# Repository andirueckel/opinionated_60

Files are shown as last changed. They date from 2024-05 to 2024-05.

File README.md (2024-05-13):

# opinionated_60

The opinionated_60 is a fixed-layout ANSI-based 60% mechanical keyboard PCB for *Cherry MX*-style switches with split `BACKSPACE`, split `RIGHT_SHIFT`, and 7u `SPACE` bar; there’s **no** option for a stepped `CAPS_LOCK` key.

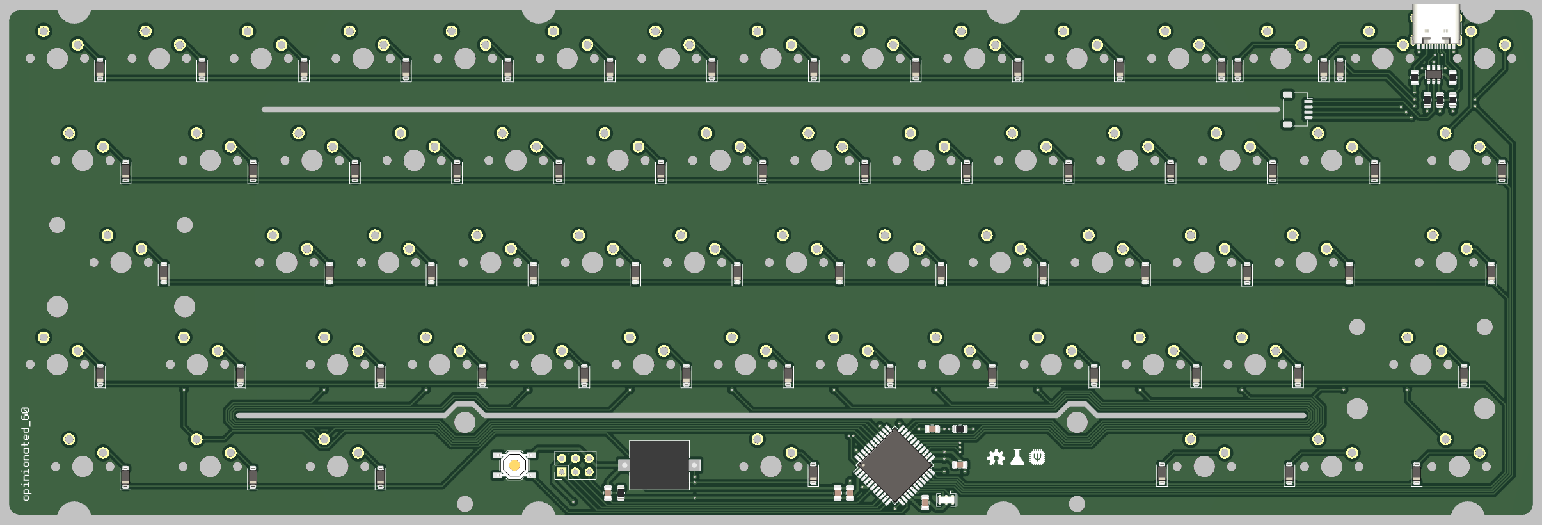
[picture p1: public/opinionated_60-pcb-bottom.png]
image/opinionated_60 pcb bottom view


The opinionated_60 is a rather modified, stripped-down, cleaned-up, and re-wired revision of the [Plain60 MKD Edition](https://github.com/manzel/plain60-mkd-edition) (ANSI version) by [manzel](https://github.com/manzel), which itself is a modified version of the [Plain60 Flex Edition](https://github.com/evyd13/plain60-flex-edition) (rev2.2) by [evyd13](https://github.com/evyd13).

The PCB design and schematics were created in [KiCad 8.0.2](https://www.kicad.org/blog/2024/04/KiCad-8.0.2-Release/).

## Features

  - Fits the SINGAKBD × TGR Unikorn and the HAYTCO CAKE60! <3
  - QMK and Vial support via the respective [firmware](/firmware)
  - No LEDs, no RGB, and no underglow!
  - *n*-key rollover (NKRO)

Also fits most universal 60% cases (Mekanisk Klippe & Fjell, KBDfans Tofu, etc.), where *fits* means *Unikorn*-style *gummy o-ring friction fit*, not traditional *tray mount* as there’s **no** holes for screws! Consider universal 60% case support experimental, and please do your research regarding your specific (use) case.

## Specifications

  - ATmega32U4-AU microcontroller
  - USB 2.0 Type-C connector *(default)*, and/or
  - JST connector for unified daughterboard *(optional)*
  - ESD protection chip and fuse to protect the PCB
  - ISP pin holes for flashing [QMK](https://github.com/qmk/qmk_firmware) and [Vial](https://github.com/vial-kb/vial-qmk) firmware
  - AST1109MLTRQ audio indicator (piezo buzzer/speaker) *(optional)*

## Layout

The 7u bottom row can be configured as *blockerless*, *WKL (winkeyless)*, or *HHKB*-style.

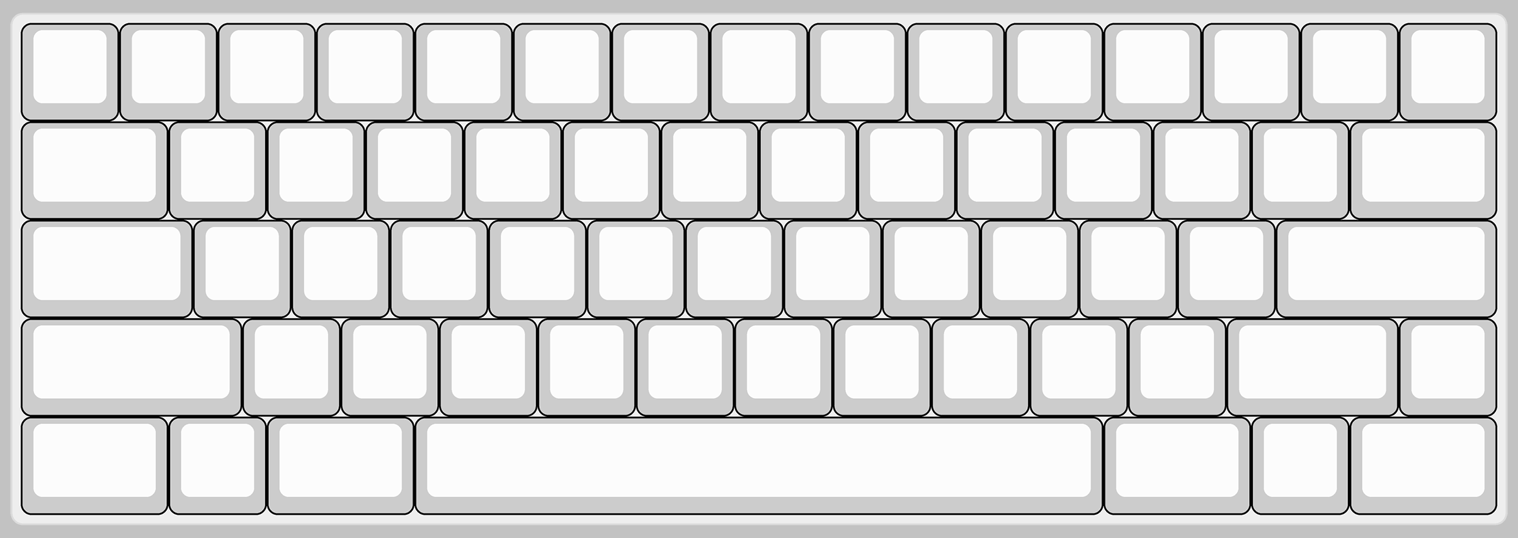
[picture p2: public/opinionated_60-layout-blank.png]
image/opinionated_60 key layout blank


## Plate

The plate drawings were created in KiCad’s PCB design tool and could be manufactured as “PCB” from e.g. aluminum base material or regular FR-4 in any color. CNC-machining the plate has not been attempted, yet.

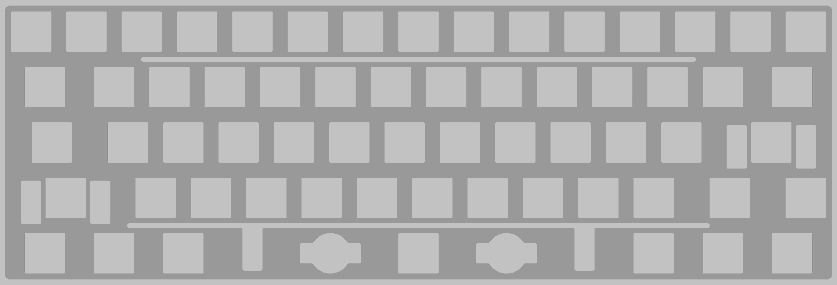
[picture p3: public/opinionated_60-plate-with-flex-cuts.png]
image/opinionated_60 plate with flex cuts


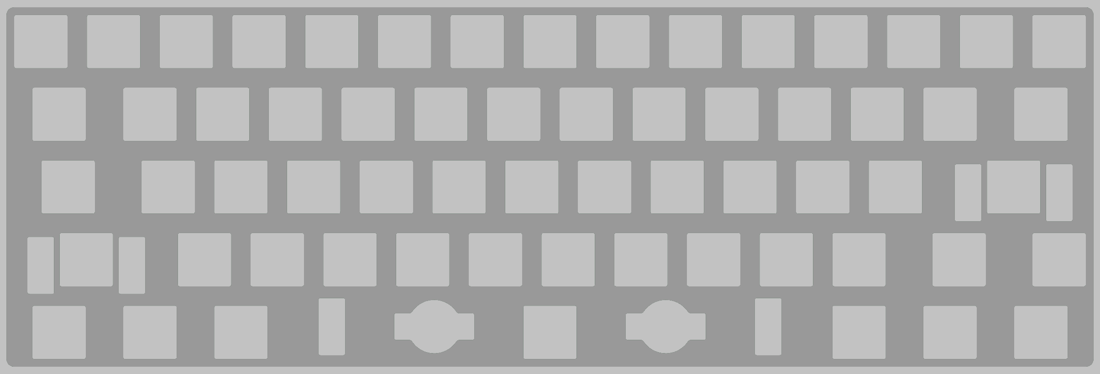
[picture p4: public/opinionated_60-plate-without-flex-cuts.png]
image/opinionated_60 plate without flex cuts


## Production

PCB and plate production files for can be found in the [Gerber](/hardware/Gerber) directory.

The production files were generated via [JLCKicadTools](https://github.com/matthewlai/JLCKicadTools).

## DISCLAIMER

Absolutely no guarantee for anything.

Use at your own risk!

## LICENSE

Creative Commons Attribution Share Alike 4.0 International (CC-BY-SA-4.0)

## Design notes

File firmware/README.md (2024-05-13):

# opinionated_60

The [opinionated_60](/) is a fixed-layout ANSI-based 60% mechanical keyboard PCB for *Cherry MX*-style switches with split `BACKSPACE`, split `RIGHT_SHIFT`, and 7u `SPACE` bar; there’s **no** option for a stepped `CAPS_LOCK` key.

image/opinionated_60 pcb bottom view

## QMK

> [!NOTE]
> The following commands needs to be executed in [`qmk_firmware`](https://github.com/qmk/qmk_firmware) context.

Navigate to your local `qmk_firmware` directory/repository:

    cd ~/path/to/qmk_firmware/

Let `qmk_firmware` know about the opinionated_60 keyboard:

    ln -s ~/path/to/opinionated_60/firmware ./keyboards/opinionated_60

Make example for this keyboard (after setting up your build environment):

    make opinionated_60:default

Flashing example for this keyboard:

    make opinionated_60:default:flash

See the QMK [build environment setup](https://docs.qmk.fm/#/getting_started_build_tools) and the [make instructions](https://docs.qmk.fm/#/getting_started_make_guide) for more information.

Brand new to QMK? Start with our [Complete Newbs Guide](https://docs.qmk.fm/#/newbs).

## Vial

> [!NOTE]
> The following commands needs to be executed in [`vial-qmk`](https://github.com/vial-kb/vial-qmk) context.

Navigate to your local `vial-qmk` directory/repository:

    cd ~/path/to/vial-qmk/

Let `vial-qmk` know about the opinionated_60 keyboard:

    ln -s ~/path/to/opinionated_60/firmware ./keyboards/opinionated_60

Make example for this keyboard (after setting up your build environment):

    make opinionated_60:vial

Flashing example for this keyboard:

    make opinionated_60:vial:flash

See the Vial [build environment setup](https://get.vial.today/docs/porting-to-vial.html#1-prepare-your-build-environment) and the [make instructions](https://get.vial.today/docs/porting-to-vial.html#1-prepare-your-build-environment) for more information.

Brand new to Vial/QMK? Start with the QMK [Complete Newbs Guide](https://docs.qmk.fm/#/newbs).

> [!NOTE]
> The Vial [secure unlock combination](https://get.vial.today/docs/porting-to-vial.html#6-set-up-a-secure-unlock-combination) is defined in [`/firmware/keymaps/vial/config.h`](/firmware/keymaps/vial/config.h).

## Bootloader

There’s two ways to enter the bootloader:

- **Physical reset button**: Press/Hold the button on the back of the PCB when connecting the USB.
- **Bootmagic reset key**: Press/Hold the `ENTER` key/switch on the keyboard when connecting the USB.

> [!NOTE]
> The [Bootmagic reset key](https://docs.qmk.fm/#/reference_info_json?id=bootmagic) is defined in [`/firmware/info.json`](/firmware/info.json).

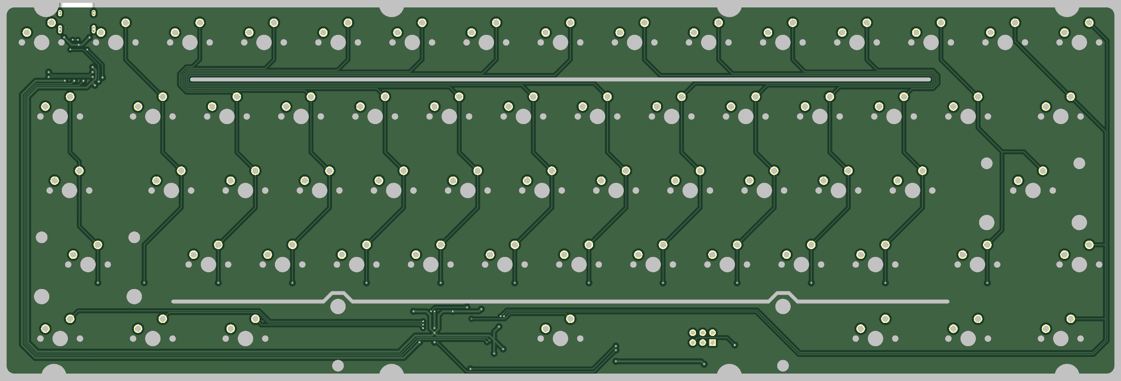
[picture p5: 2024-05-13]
public/opinionated_60-pcb-top.png

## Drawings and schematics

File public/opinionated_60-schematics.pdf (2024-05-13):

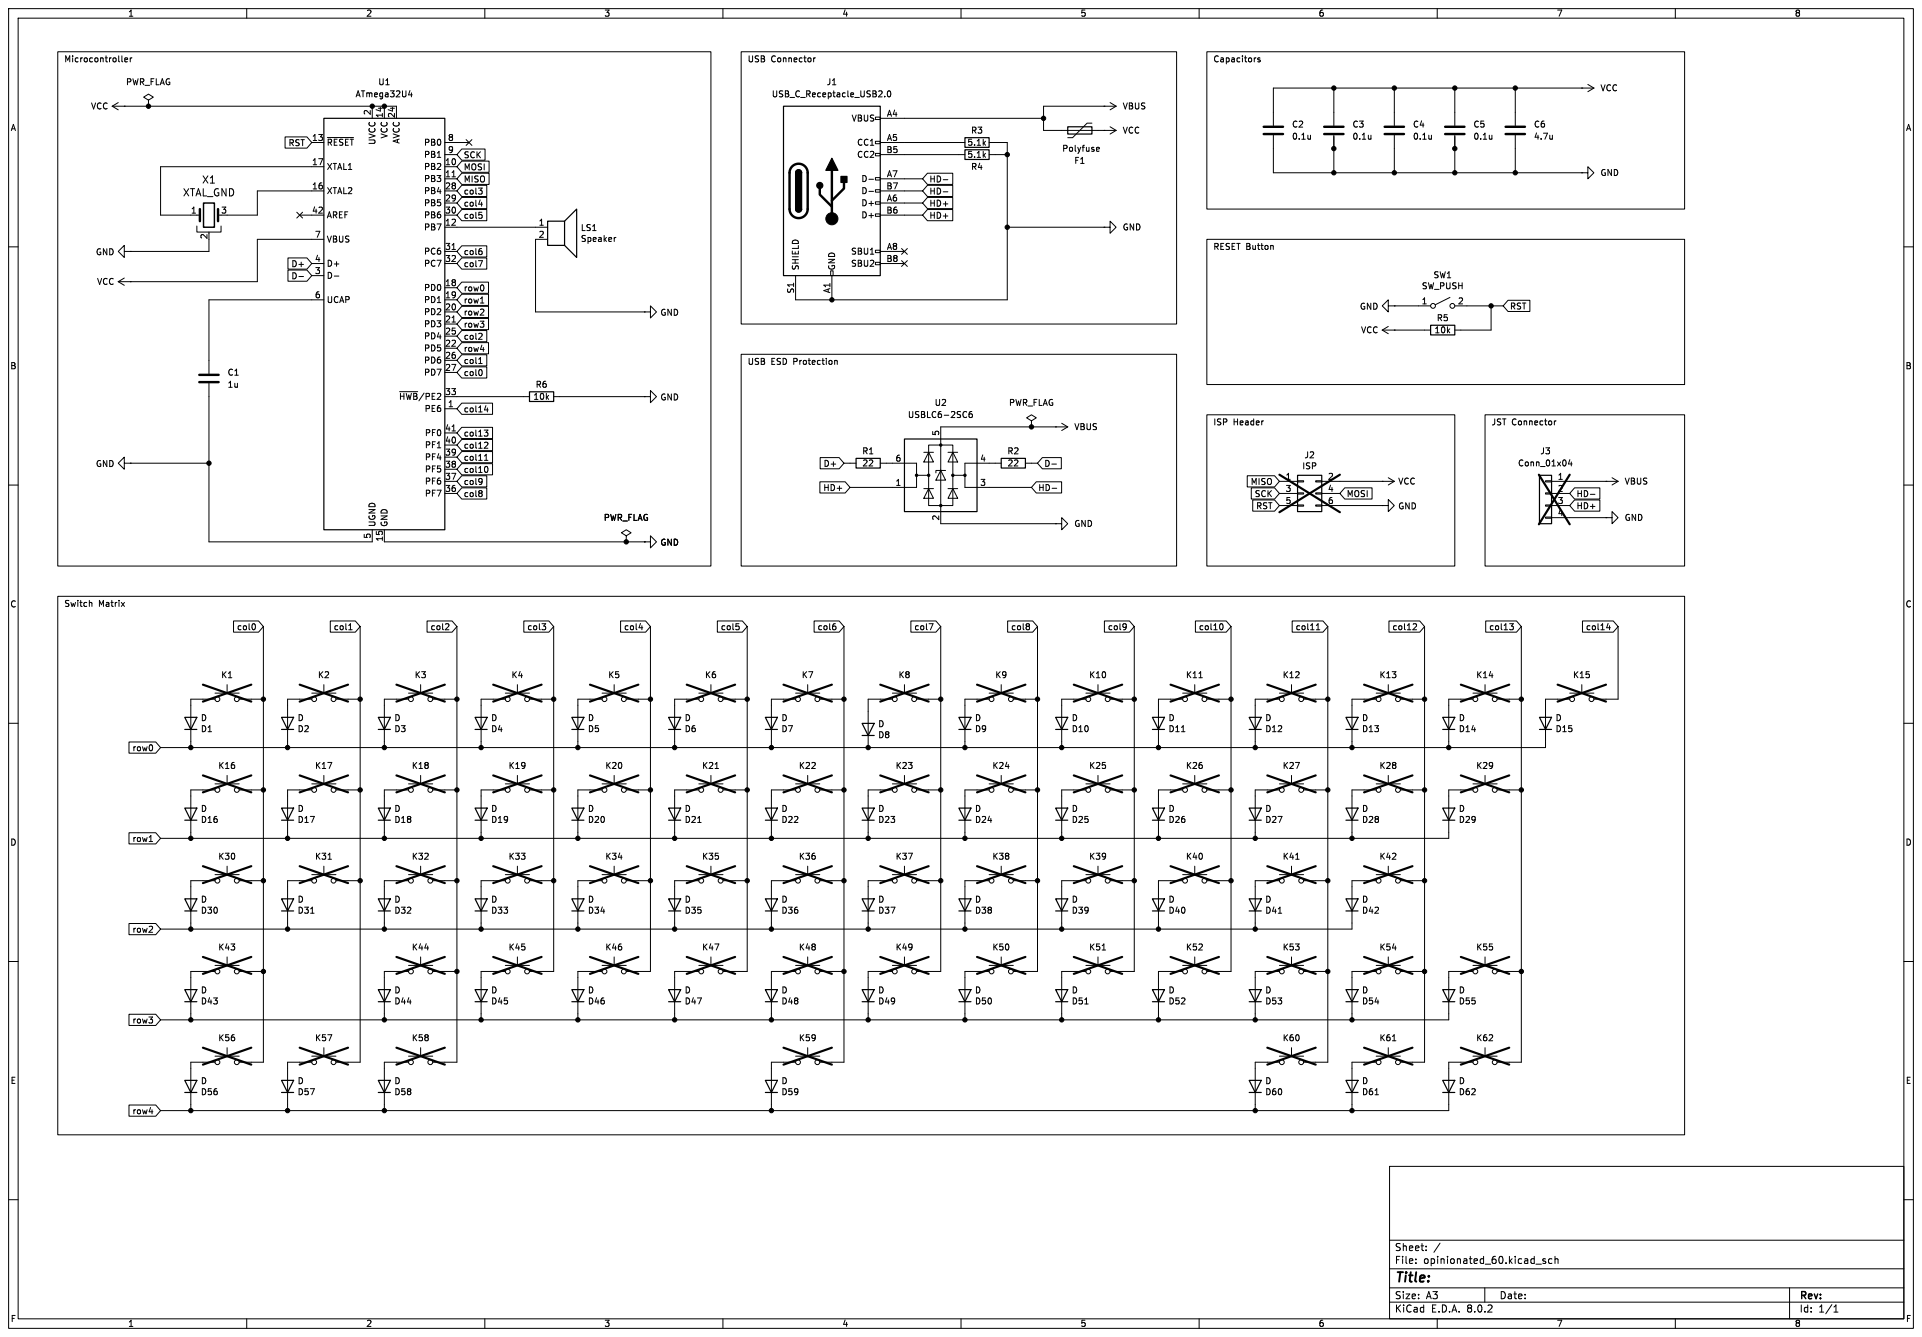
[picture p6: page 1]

2 PD2 20 PD3 21 PD5 22 AVCC 24 PD4 25 PD6 26 PD7 27 PB4 28 PB5 29 D- 3 PB6 30 PC6 31 PC7 32 ~{HWB}/PE233 PF7 36 PF6 37 PF5 38 PF4 39 D+ 4 PF1 40 PF0 41 AREF 42 UGND

Id: 1/1 Title: File: opinionated_60.kicad_sch Sheet: /

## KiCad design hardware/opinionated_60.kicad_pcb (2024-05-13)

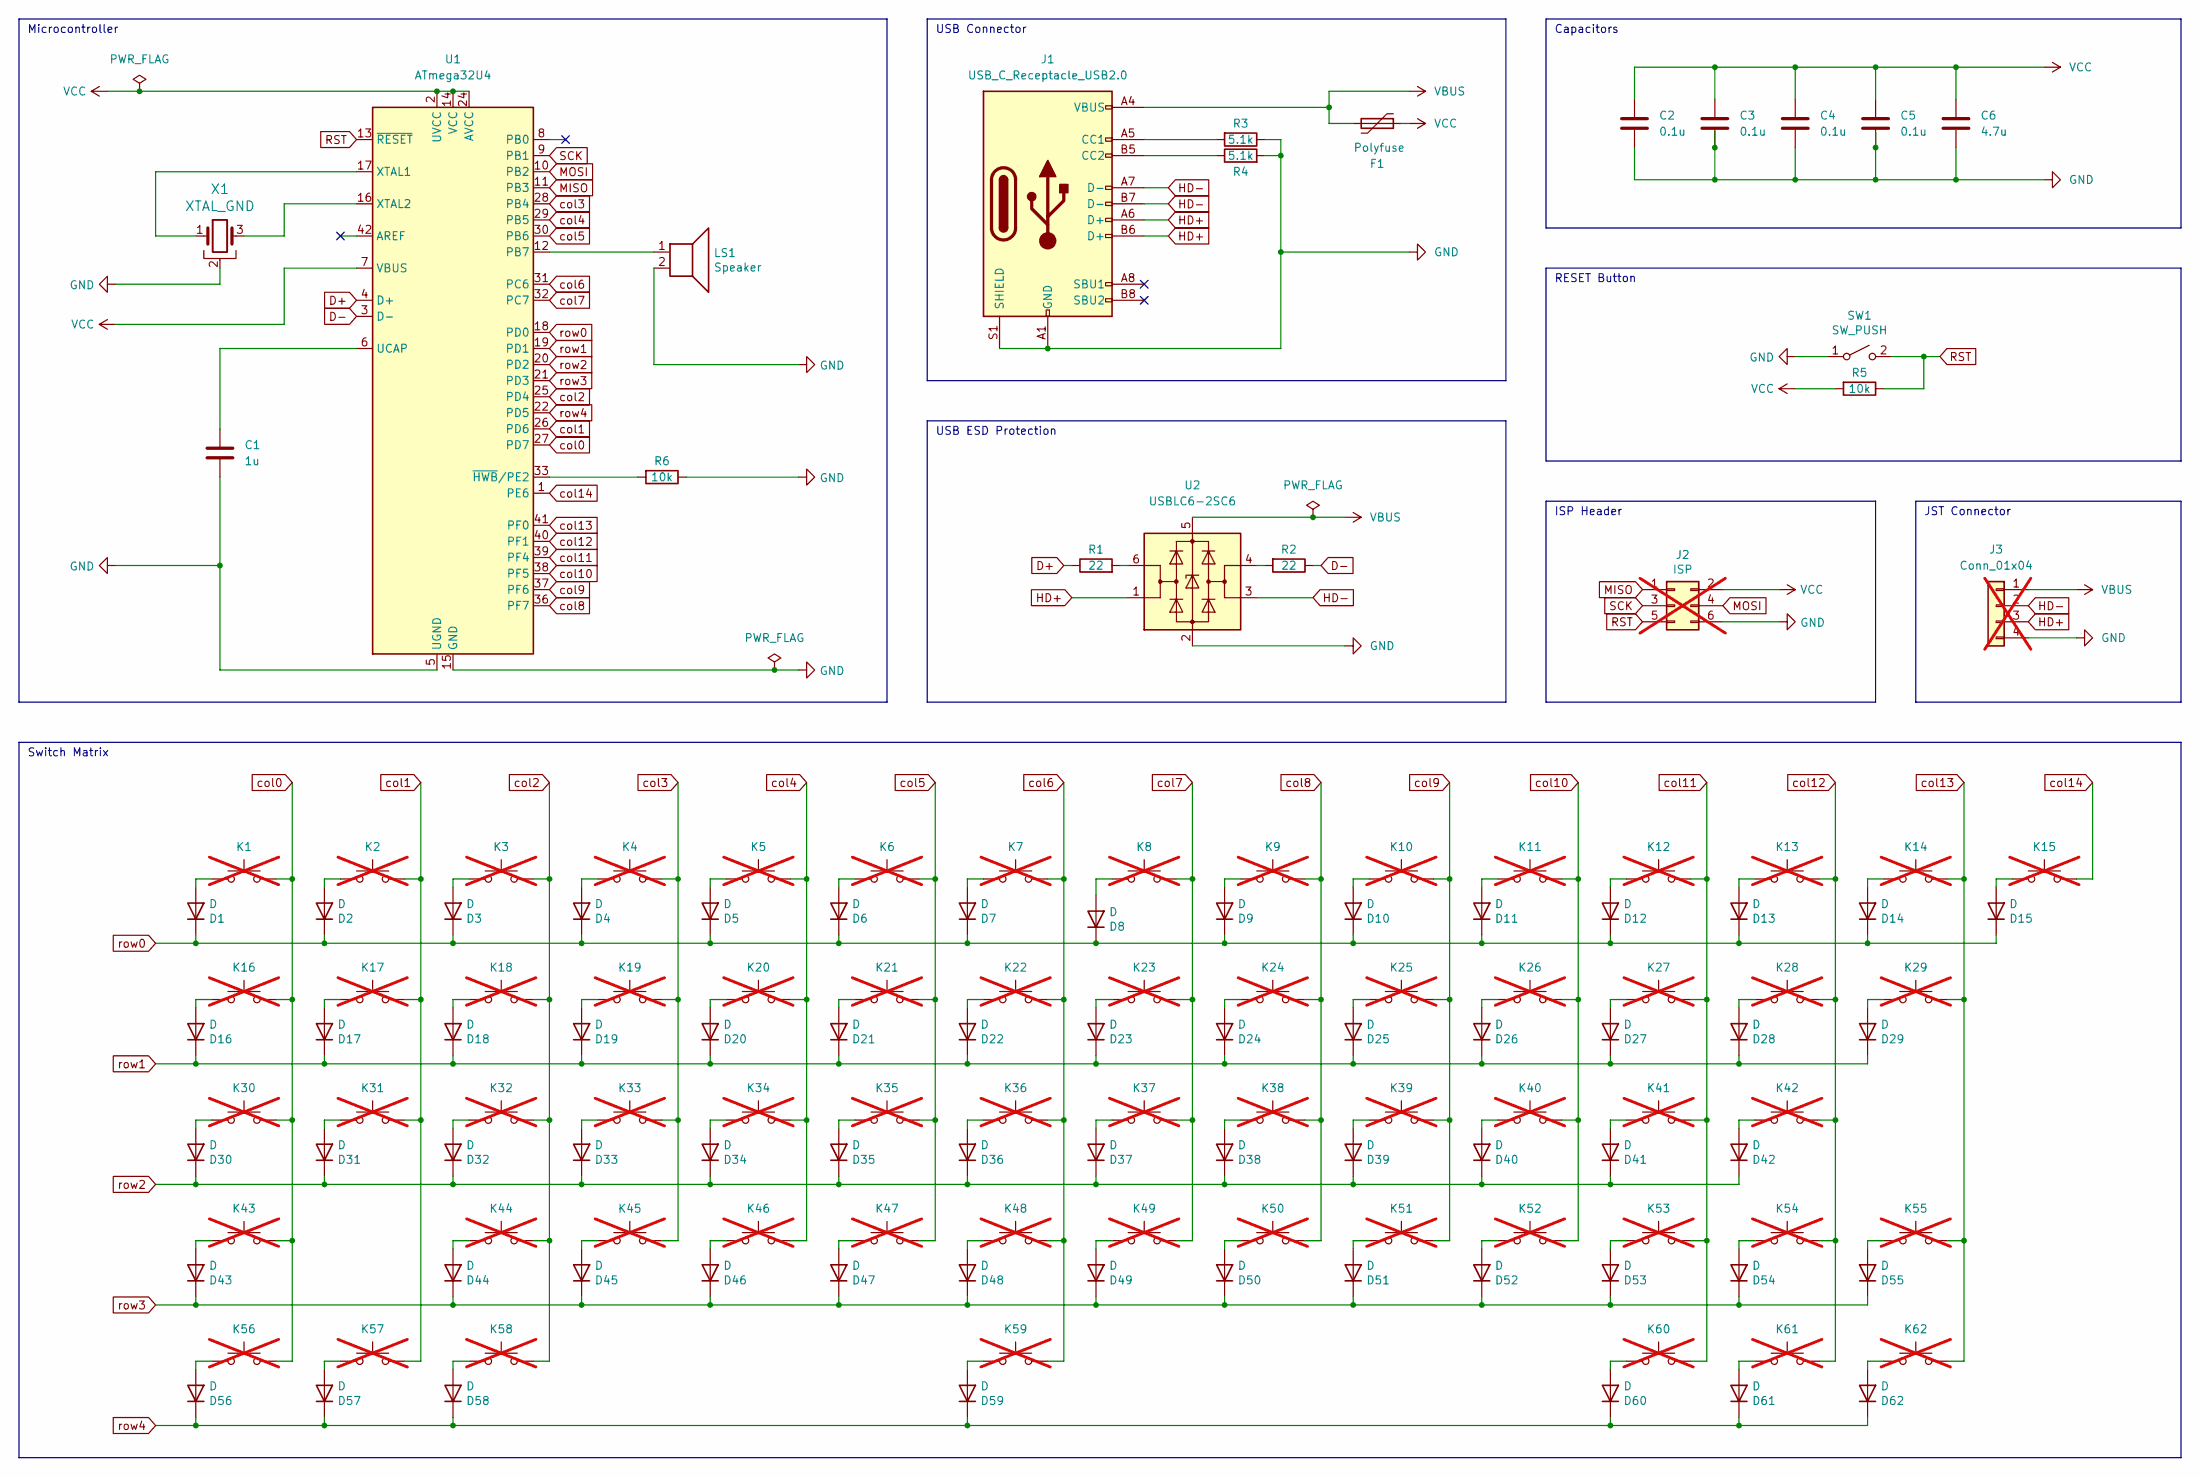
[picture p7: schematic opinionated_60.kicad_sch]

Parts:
C1: 1u; C_0805_2012Metric; LCSC part number C28323
C2, C3, C4, C5: 0.1u; C_0805_2012Metric; LCSC part number C49678
C6: 4.7u; C_0805_2012Metric; LCSC part number C1779
D1, D2, D3, D4, D5, D6, D7, D8, D9, D10, D11, D12, D13, D14, D15, D16, D17, D18, D19, D20, D21, D22, D23, D24, D25, D26, D27, D28, D29, D30, D31, D32, D33, D34, D35, D36, D37, D38, D39, D40, D41, D42, D43, D44, D45, D46, D47, D48, D49, D50, D51, D52, D53, D54, D55, D56, D57, D58, D59, D60, D61, D62: D; D_SOD-123; LCSC part number C2099
F1: Polyfuse; Fuse_0805_2012Metric; LCSC part number C261942
J1: USB_C_Receptacle_USB2.0; USB_C_Receptacle_HRO_TYPE-C-31-M-12; LCSC part number C165948
J2: ISP; PinHeader_2x03_P2.54mm_Vertical; not fitted
J3: Conn_01x04; JST_SH_SM04B-SRSS-TB_1x04-1MP_P1.00mm_Horizontal; LCSC part number C160404; not fitted
K1, K2, K3, K4, K5, K6, K7, K8, K9, K10, K11, K12, K13, K14, K15, K17, K18, K19, K20, K21, K22, K23, K24, K25, K26, K27, K28, K31, K32, K33, K34, K35, K36, K37, K38, K39, K40, K41, K44, K45, K46, K47, K48, K49, K50, K51, K52, K53, K55, K57, K61: SW_KEY; SW_Cherry_MX_1.00u_PCB; not fitted
K16, K29, K56, K58, K60, K62: SW_KEY; SW_Cherry_MX_1.50u_PCB; not fitted
K30, K54: SW_KEY; SW_Cherry_MX_1.75u_PCB; not fitted
K42, K43: SW_KEY; SW_Cherry_MX_2.25u_PCB; not fitted
K59: SW_KEY; SW_Cherry_MX_7.00u_PCB; not fitted
LS1: Speaker; Buzzer_Mallory_AST1109MLTRQ; LCSC part number C391036
R1, R2: 22; R_0805_2012Metric; LCSC part number C17561
R3, R4: 5.1k; R_0805_2012Metric; LCSC part number C27834
R5, R6: 10k; R_0805_2012Metric; LCSC part number C17414
SW1: SW_PUSH; SW_SPST_TL3342; LCSC part number C92584
U1: ATmega32U4; TQFP-44_10x10mm_P0.8mm; LCSC part number C44854
U2: USBLC6-2SC6; SOT-23-6; LCSC part number C7519
X1: XTAL_GND; Resonator_SMD_Murata_CSTxExxV-3Pin_3.0x1.1mm; LCSC part number C783275

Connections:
D+: R1.1, U1.4 (D+)
D-: R2.1, U1.3 (D-)
GND: C1.2, C2.2, C3.2, C4.2, C5.2, C6.2, J1.A1 (GND), J1.A12 (GND), J1.B1 (GND), J1.B12 (GND), J1.S1 (SHIELD), J2.6, J3.4, LS1.2, R3.1, R4.2, R6.1, SW1.1 (A), U1.5 (UGND), U1.15 (GND), U1.23 (GND), U1.35 (GND), U1.43 (GND), U2.2 (GND), X1.2
HD+: J1.A6 (D+), J1.B6 (D+), J3.3, U2.1 (I/O1)
HD-: J1.A7 (D-), J1.B7 (D-), J3.2, U2.3 (I/O2)
MISO: J2.1, U1.11 (PB3)
MOSI: J2.4, U1.10 (PB2)
unnamed: D1.2 (A), K1.2
unnamed: D2.2 (A), K2.2
unnamed: D3.2 (A), K3.2
unnamed: D4.2 (A), K4.2
unnamed: D5.2 (A), K5.2
unnamed: D6.2 (A), K6.2
unnamed: D7.2 (A), K7.2
unnamed: D8.2 (A), K8.2
unnamed: D9.2 (A), K9.2
unnamed: D10.2 (A), K10.2
unnamed: D11.2 (A), K11.2
unnamed: D12.2 (A), K12.2
unnamed: D13.2 (A), K13.2
unnamed: D14.2 (A), K14.2
unnamed: D15.2 (A), K15.2
unnamed: D16.2 (A), K16.2
unnamed: D17.2 (A), K17.2
unnamed: D18.2 (A), K18.2
unnamed: D19.2 (A), K19.2
unnamed: D20.2 (A), K20.2
unnamed: D21.2 (A), K21.2
unnamed: D22.2 (A), K22.2
unnamed: D23.2 (A), K23.2
unnamed: D24.2 (A), K24.2
unnamed: D25.2 (A), K25.2
unnamed: D26.2 (A), K26.2
unnamed: D27.2 (A), K27.2
unnamed: D28.2 (A), K28.2
unnamed: D29.2 (A), K29.2
unnamed: D30.2 (A), K30.2
unnamed: D31.2 (A), K31.2
unnamed: D32.2 (A), K32.2
unnamed: D33.2 (A), K33.2
unnamed: D34.2 (A), K34.2
unnamed: D35.2 (A), K35.2
unnamed: D36.2 (A), K36.2
unnamed: D37.2 (A), K37.2
unnamed: D38.2 (A), K38.2
unnamed: D39.2 (A), K39.2
unnamed: D40.2 (A), K40.2
unnamed: D41.2 (A), K41.2
unnamed: D42.2 (A), K42.2
unnamed: D43.2 (A), K43.2
unnamed: D44.2 (A), K44.2
unnamed: D45.2 (A), K45.2
unnamed: D46.2 (A), K46.2
unnamed: D47.2 (A), K47.2
unnamed: D48.2 (A), K48.2
unnamed: D49.2 (A), K49.2
unnamed: D50.2 (A), K50.2
unnamed: D51.2 (A), K51.2
unnamed: D52.2 (A), K52.2
unnamed: D53.2 (A), K53.2
unnamed: D54.2 (A), K54.2
unnamed: D55.2 (A), K55.2
unnamed: D56.2 (A), K56.2
unnamed: D57.2 (A), K57.2
unnamed: D58.2 (A), K58.2
unnamed: D59.2 (A), K59.2
unnamed: D60.2 (A), K60.2
unnamed: D61.2 (A), K61.2
unnamed: D62.2 (A), K62.2
unnamed: J1.A5 (CC1), R3.2
unnamed: J1.B5 (CC2), R4.1
unnamed: R1.2, U2.6 (I/O1)
unnamed: R2.2, U2.4 (I/O2)
unnamed: LS1.1, U1.12 (PB7)
unnamed: C1.1, U1.6 (UCAP)
unnamed: U1.17 (XTAL1), X1.1
unnamed: U1.16 (XTAL2), X1.3
unnamed: R6.2, U1.33 (~HWB/PE2)
RST: J2.5, R5.1, SW1.2 (B), U1.13 (~RESET)
SCK: J2.3, U1.9 (PB1)
VBUS: F1.2, J1.A4 (VBUS), J1.A9 (VBUS), J1.B4 (VBUS), J1.B9 (VBUS), J3.1, U2.5 (VBUS)
VCC: C2.1, C3.1, C4.1, C5.1, C6.1, F1.1, J2.2, R5.2, U1.2 (UVCC), U1.7 (VBUS), U1.14 (VCC), U1.24 (AVCC), U1.34 (VCC), U1.44 (AVCC)
col0: K1.1, K16.1, K30.1, K43.1, K56.1, U1.27 (PD7)
col1: K2.1, K17.1, K31.1, K57.1, U1.26 (PD6)
col2: K3.1, K18.1, K32.1, K44.1, K58.1, U1.25 (PD4)
col3: K4.1, K19.1, K33.1, K45.1, U1.28 (PB4)
col4: K5.1, K20.1, K34.1, K46.1, U1.29 (PB5)
col5: K6.1, K21.1, K35.1, K47.1, U1.30 (PB6)
col6: K7.1, K22.1, K36.1, K48.1, K59.1, U1.31 (PC6)
col7: K8.1, K23.1, K37.1, K49.1, U1.32 (PC7)
col8: K9.1, K24.1, K38.1, K50.1, U1.36 (PF7)
col9: K10.1, K25.1, K39.1, K51.1, U1.37 (PF6)
col10: K11.1, K26.1, K40.1, K52.1, U1.38 (PF5)
col11: K12.1, K27.1, K41.1, K53.1, K60.1, U1.39 (PF4)
col12: K13.1, K28.1, K42.1, K54.1, K61.1, U1.40 (PF1)
col13: K14.1, K29.1, K55.1, K62.1, U1.41 (PF0)
col14: K15.1, U1.1 (PE6)
row0: D1.1 (K), D2.1 (K), D3.1 (K), D4.1 (K), D5.1 (K), D6.1 (K), D7.1 (K), D8.1 (K), D9.1 (K), D10.1 (K), D11.1 (K), D12.1 (K), D13.1 (K), D14.1 (K), D15.1 (K), U1.18 (PD0)
row1: D16.1 (K), D17.1 (K), D18.1 (K), D19.1 (K), D20.1 (K), D21.1 (K), D22.1 (K), D23.1 (K), D24.1 (K), D25.1 (K), D26.1 (K), D27.1 (K), D28.1 (K), D29.1 (K), U1.19 (PD1)
row2: D30.1 (K), D31.1 (K), D32.1 (K), D33.1 (K), D34.1 (K), D35.1 (K), D36.1 (K), D37.1 (K), D38.1 (K), D39.1 (K), D40.1 (K), D41.1 (K), D42.1 (K), U1.20 (PD2)
row3: D43.1 (K), D44.1 (K), D45.1 (K), D46.1 (K), D47.1 (K), D48.1 (K), D49.1 (K), D50.1 (K), D51.1 (K), D52.1 (K), D53.1 (K), D54.1 (K), D55.1 (K), U1.21 (PD3)
row4: D56.1 (K), D57.1 (K), D58.1 (K), D59.1 (K), D60.1 (K), D61.1 (K), D62.1 (K), U1.22 (PD5)

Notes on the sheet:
USB ESD Protection
RESET Button
JST Connector
Switch Matrix
Microcontroller
Capacitors
ISP Header
USB Connector

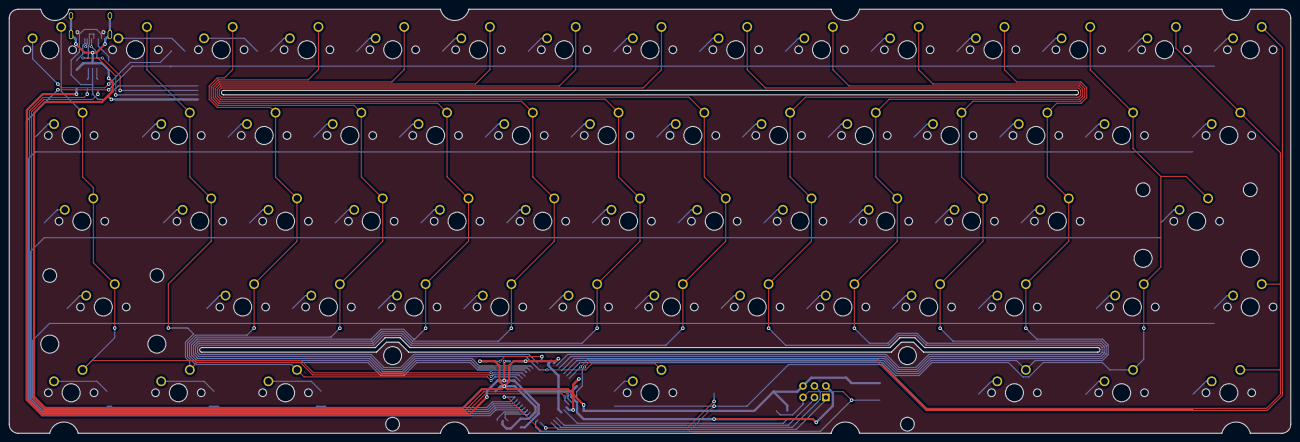
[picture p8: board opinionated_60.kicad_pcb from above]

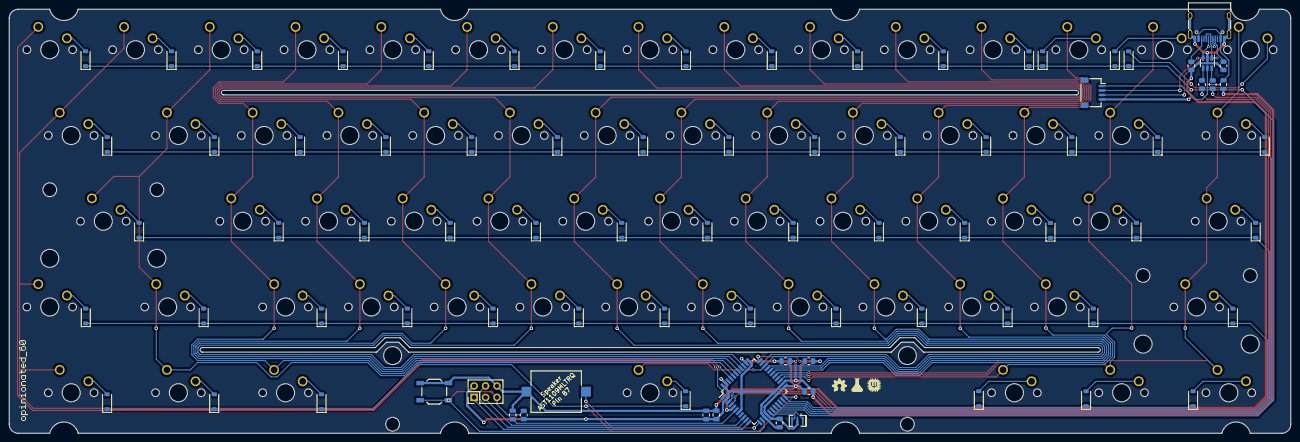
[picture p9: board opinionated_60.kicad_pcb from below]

Board: 2 copper layers, 284.7 x 94.2 mm, 149 parts (87 on the bottom side), 102 nets.

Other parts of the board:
LOGO_OSHW: LOGO; LOGO_OSHW
LOGO_QMK: LOGO; LOGO_QMK
LOGO_Vial: LOGO; LOGO_Vial
LOGO_opinionated_60: LOGO; LOGO_opinionated_60
